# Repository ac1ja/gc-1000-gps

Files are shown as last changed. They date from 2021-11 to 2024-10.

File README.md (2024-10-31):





# Firmware
Requires platformio, make

Install build deps
```
# Ubuntu/Debian
sudo apt install build-essential make

# Platformio install script, see https://docs.platformio.org/en/latest/core/installation/methods/installer-script.html
python3 -c "$(curl -fsSL https://raw.githubusercontent.com/platformio/platformio/master/scripts/get-platformio.py)"
```

Or install platformio from [here](https://platformio.org/install), this project assumes
only pio core but the ide integrations will also work

## Build

Clone and build the repo
```
git clone --recurse-submodules https://github.com/ac1ja/gc-1000-gps.git
cd firmware
make
make flash
```

Debugging notes
```
git clone --recurse-submodules https://github.com/ac1ja/gc-1000-gps.git
cd firmware
make debug
```

See docs for full instruction! https://gc-1000-gps.readthedocs.io/en/latest/

# Hardware

## Install KiCAD

Install KiCAD from [here](https://www.kicad.org/download/), find the hardware files under `hardware`

# Where is everything?

```shell
├── cad                     # CAD and design files
├── firmware                # Software and Firmware source code
└── hardware                # PCB And component design files
    └── gc-1000-gps         # GC-1000-gps board!
        └── Libraries       # External kicad libs
```

# Docs
Docs written with sphinx for use with readthedocs.
Info here https://docs.readthedocs.io/en/stable/intro/getting-started-with-sphinx.html

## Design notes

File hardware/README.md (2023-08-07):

# Hardware

All the hardware for the inverted pendulum is made with (KiCAD)[https://www.kicad.org/]!

All the automation for this project is done with (KiBot)[https://github.com/INTI-CMNB/KiBot]

## Getting Started

Always clone this repo using submodules!

```shell
git clone --recurse-submodules https://github.com/ac1ja/gc-1000-gps.git
```

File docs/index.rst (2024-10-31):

.. GC-1000-GPS documentation master file, created by
   sphinx-quickstart on Thu Jul 22 12:23:04 2021.
   You can adapt this file completely to your liking, but it should at least
   contain the root `toctree` directive.

Welcome to GC-1000-GPS's documentation!
=======================================

.. toctree::
   :maxdepth: 3
   :glob:

   usage/getting-started
   assembly/circuit_board
   assembly/firmware
   usage/usage
   development/contributing

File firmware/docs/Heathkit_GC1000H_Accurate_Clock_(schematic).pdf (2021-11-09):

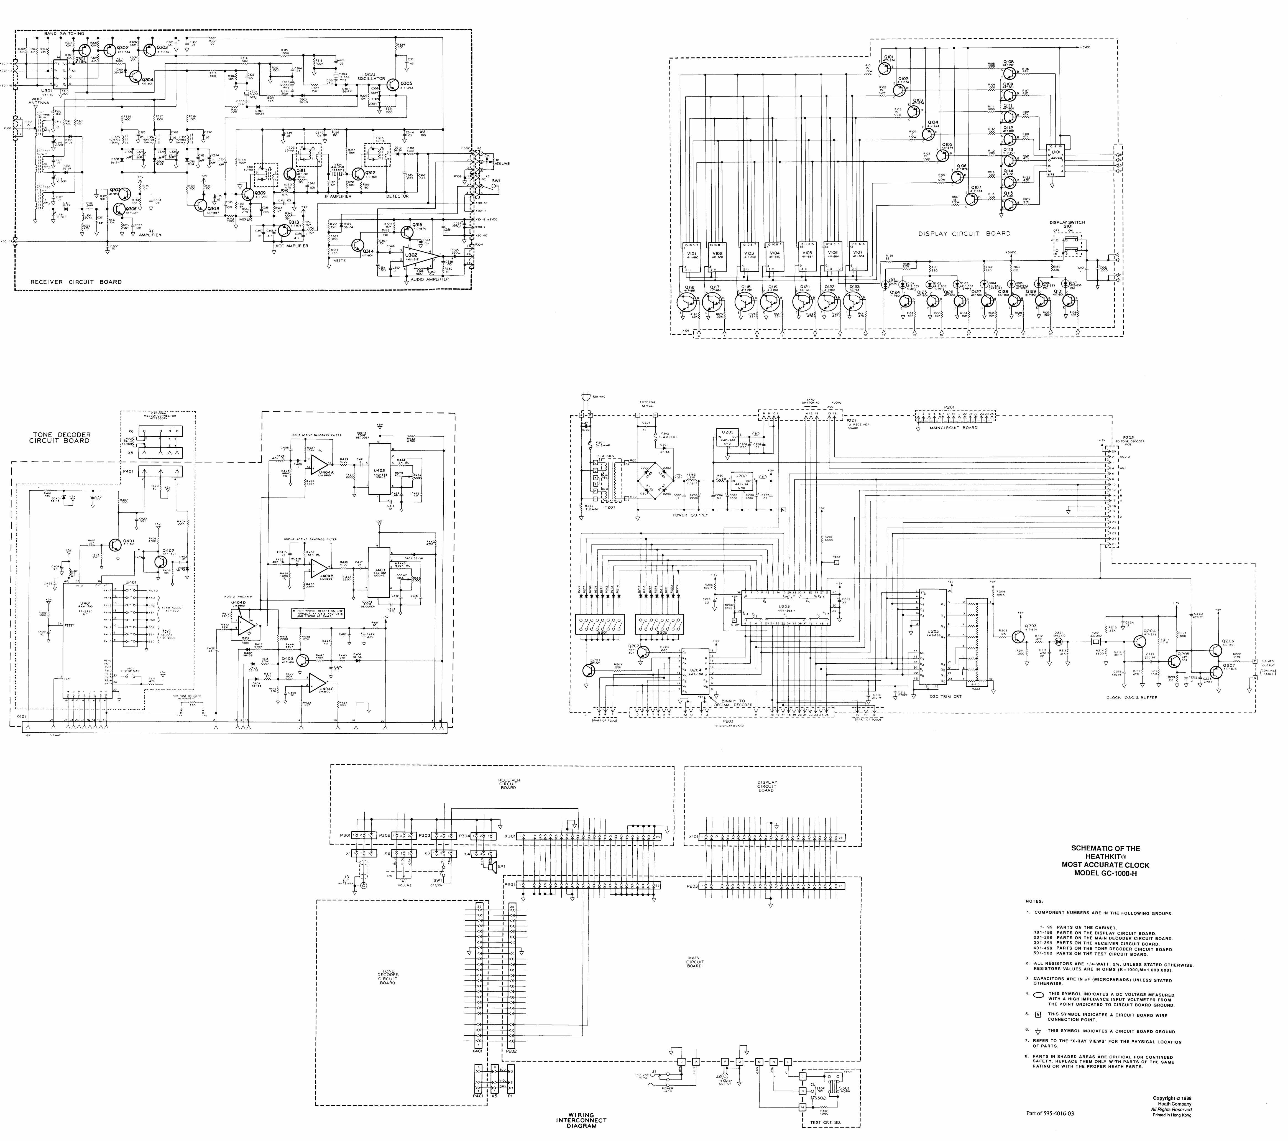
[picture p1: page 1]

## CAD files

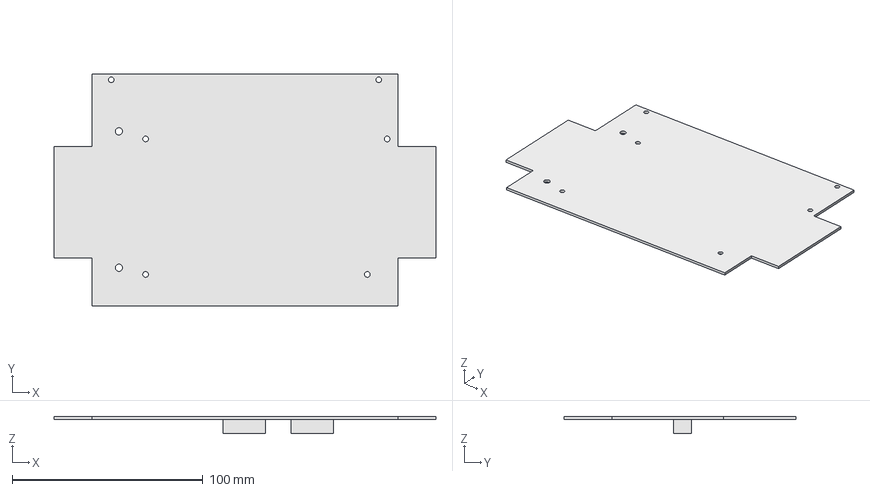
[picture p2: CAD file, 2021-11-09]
cad/gc-1000-gps_mainboardMask.FCStd
200.2 x 121.5 x 9.05 mm

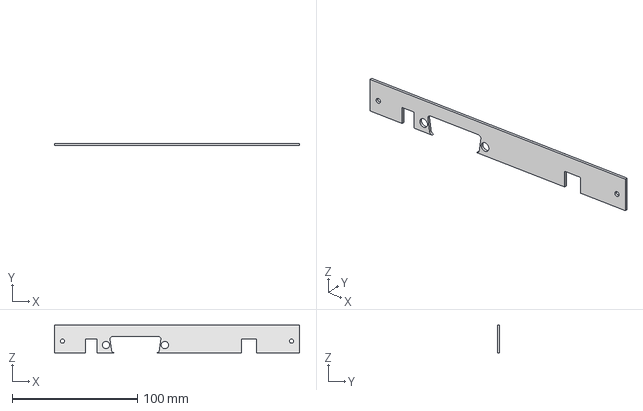
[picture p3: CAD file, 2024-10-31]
cad/gc-1000-gps_IO_Shield.FCStd
195.6 x 1.65 x 22.0 mm

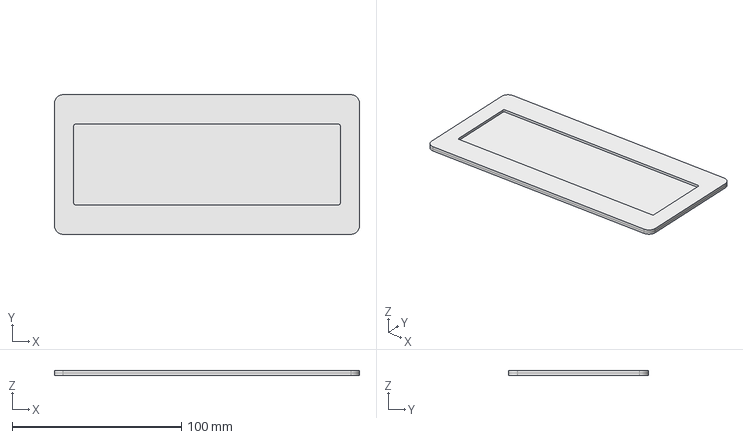
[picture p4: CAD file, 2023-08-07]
hardware/Stencil.FCStd
180.3 x 82.6 x 3.17 mm

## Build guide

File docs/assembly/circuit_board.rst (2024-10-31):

Assemble the GC-1000-GPS
========================

You've got your hands on a gc-1000-gps circuit board! Congrats! We hope you like it.

For these instructions, you will need:

* Solder and soldering iron.
* all included components.
* an `Arduino Mega <https://store.arduino.cc/usa/mega-2560-r3>`_ plugged into your computer.
* All dependencies_ required to build the code.

.. warning::
    This section of the documentation is applicable only to ``v0.2``
    boards and above, and firmware versions ``v0.2-x``.

Soldering the new board
#######################

.. note::
    It can be very helpful to install the DIP switches last, as they make it awkward when assembling the parts on the top of the board.

Prepare the board to be soldered, collect all components, heat your iron. We recomend solid core solder, and flux paste.

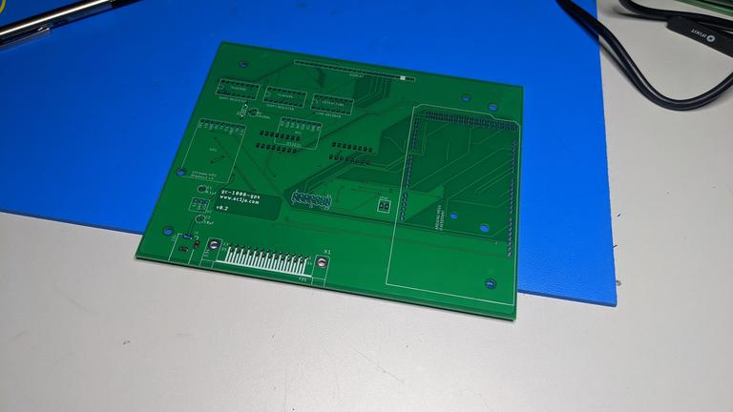
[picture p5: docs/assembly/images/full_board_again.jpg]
Full Board


I installed the chips and sockets first but a specific order is not required. 

Generally its easier to install the shorter components first.

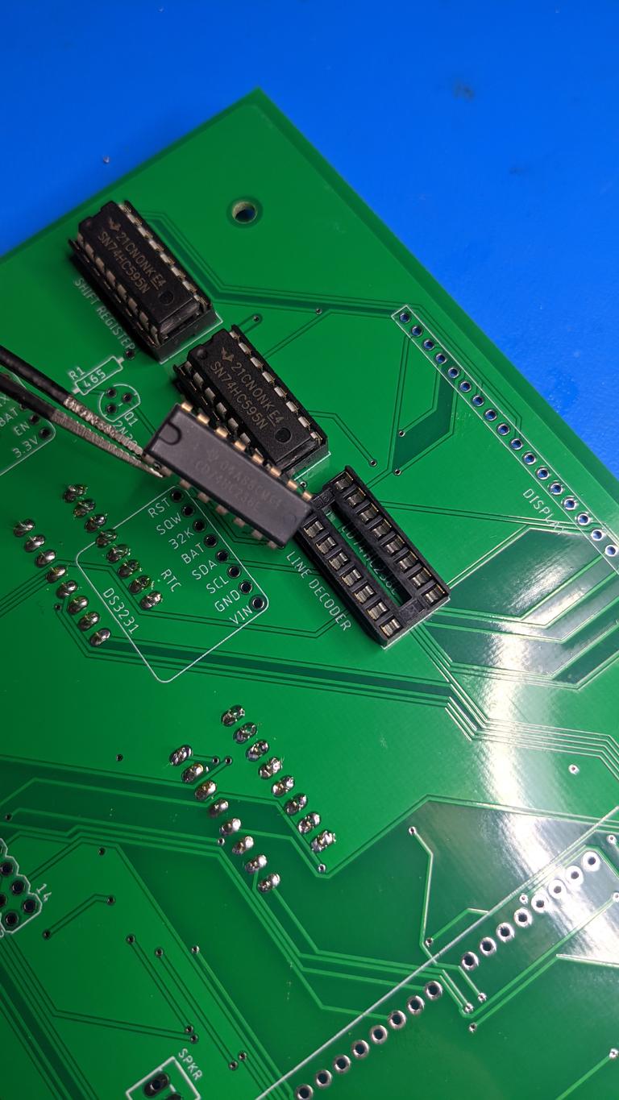
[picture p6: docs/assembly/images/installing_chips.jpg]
Installing chips


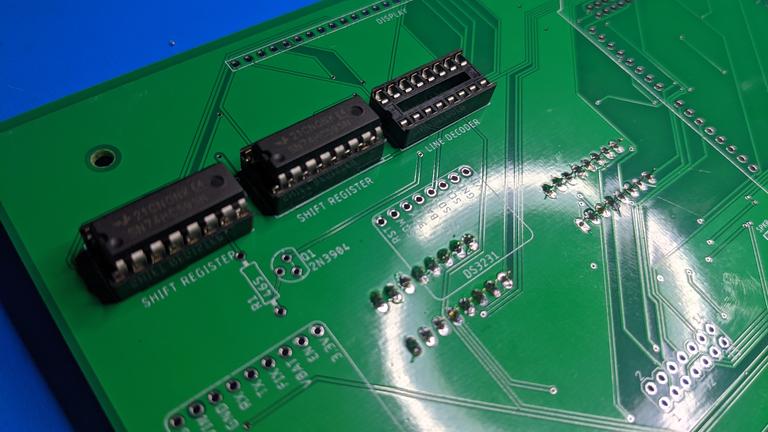
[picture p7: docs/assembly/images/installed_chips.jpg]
Chips installed


Once the chips are done, installing all of the headers are generally best.

When soldering the arduino mega pins, to assure alignment, 
it can be helpful to populate all of its pins first. Once this is done, place it on the board and solder from behind.

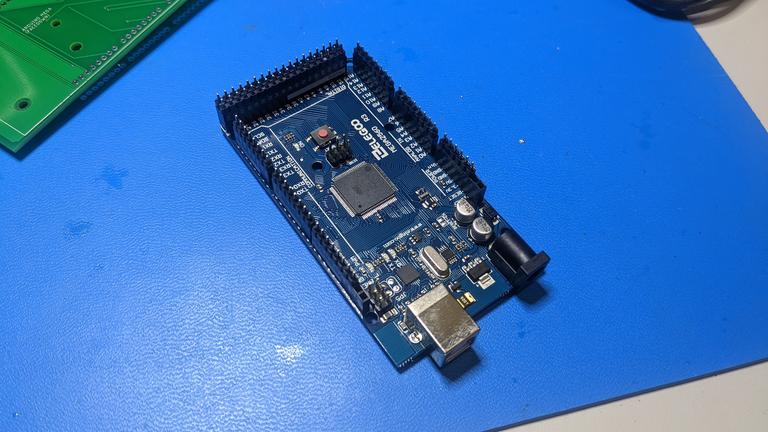
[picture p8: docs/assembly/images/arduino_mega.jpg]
Arduino Mega with pins installed


After soldering the pins, when you remove the mega, all should be straight and alligned to fit inside it.

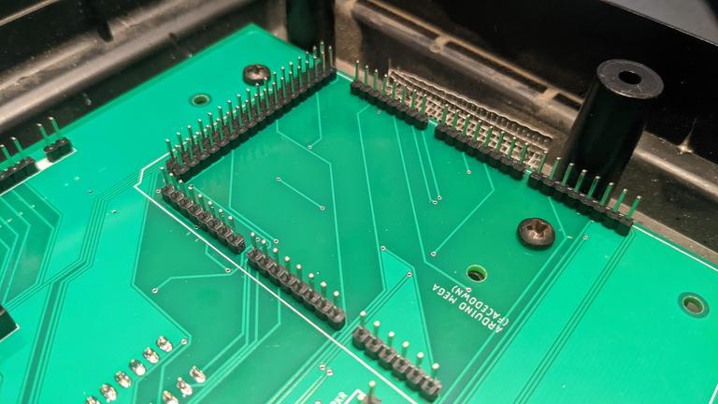
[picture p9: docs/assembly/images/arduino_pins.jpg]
Arduino Mega pins on board


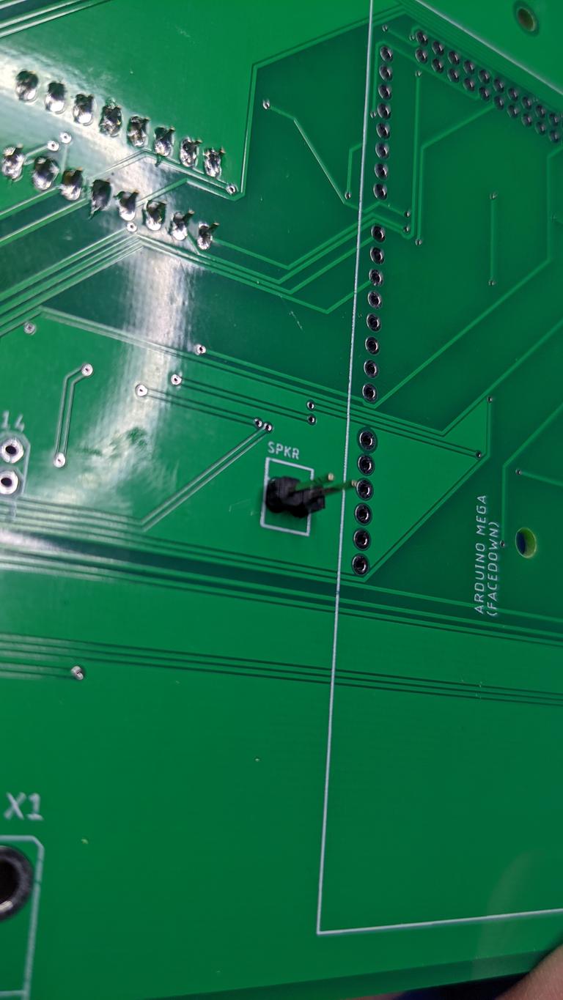
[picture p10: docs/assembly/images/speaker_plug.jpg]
Speaker pins


.. note::
    The display board also needs male header pins.

Several components such as the VRM, the GPS and the RTC need **female** header pins, install these next.

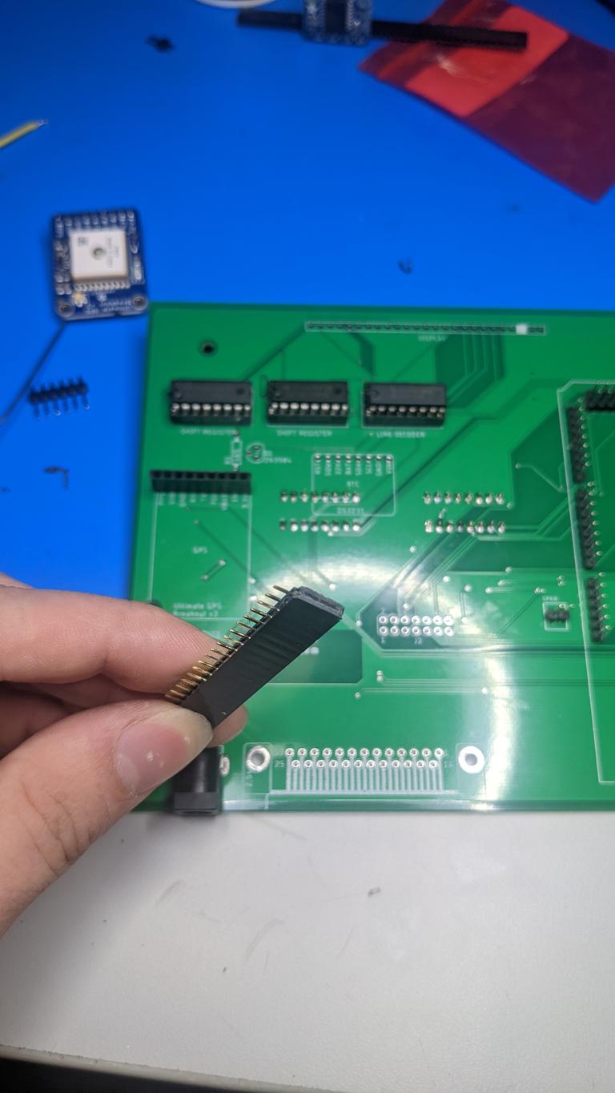
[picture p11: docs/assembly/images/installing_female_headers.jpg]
Female headers


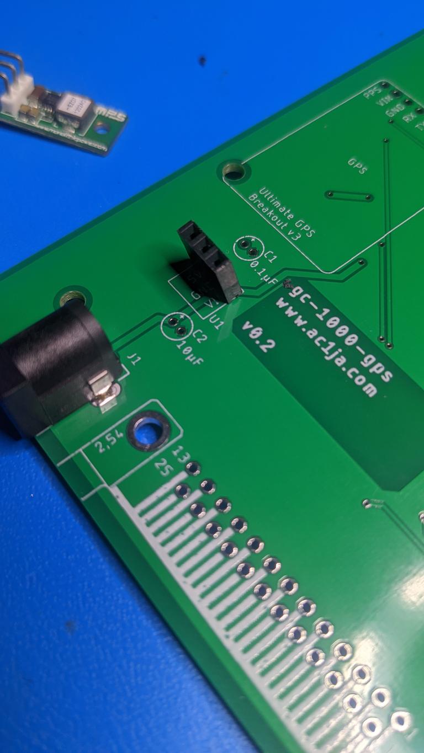
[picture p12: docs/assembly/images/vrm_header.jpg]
VRM Header


Open the packaging for the GPS and RTC from adafruit, solder on the male pins and optionally, clock battery covers.

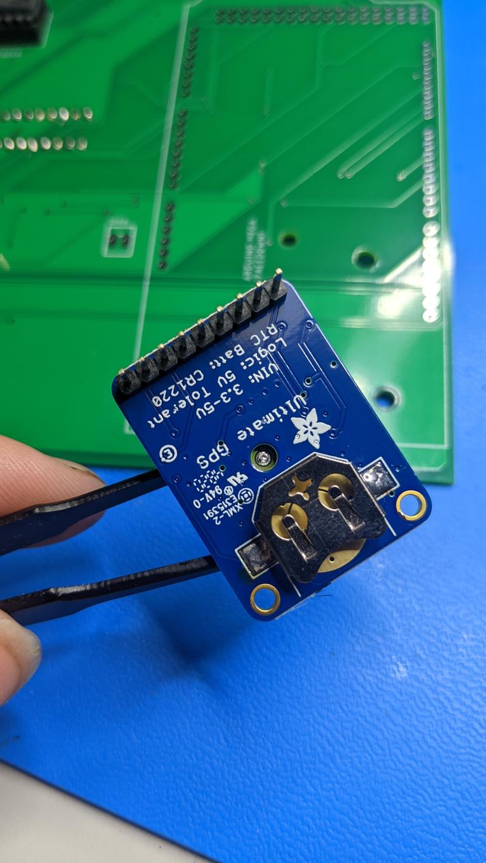
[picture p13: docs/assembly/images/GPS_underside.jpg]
GPS underside


The board is nearly complete, all components should look like this:

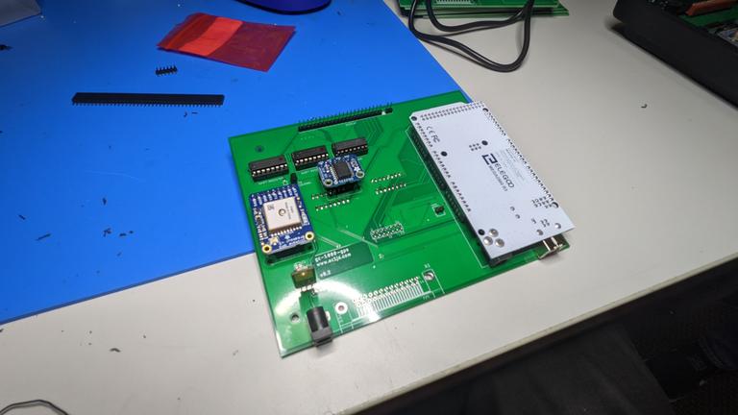
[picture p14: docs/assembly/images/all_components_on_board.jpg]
All components on board


The last step should be to install the dip switches, take note of the indicated direction.

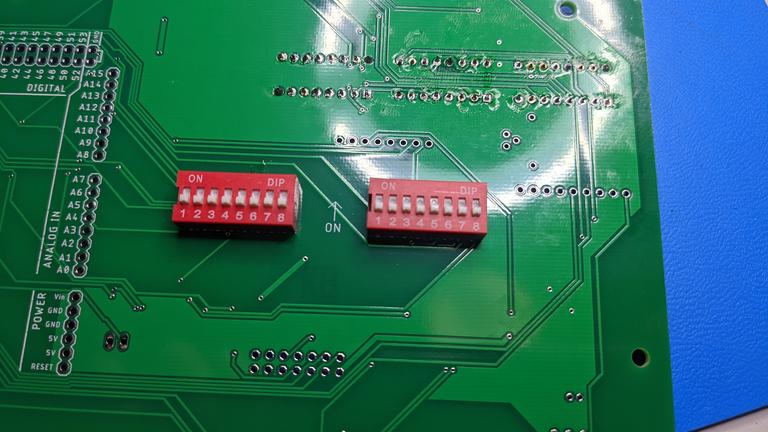
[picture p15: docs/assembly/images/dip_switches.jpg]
Dip Switches


Thats it! move onto the next step, :ref:`Dissasembly/Upgrade`.

Dissasembly/Upgrade
###################

Before we can begin assembly of your gc-1000-gps, we need to dissasemble it.

Find the four screws installed on the bottom, unscrew them to remove the cover.

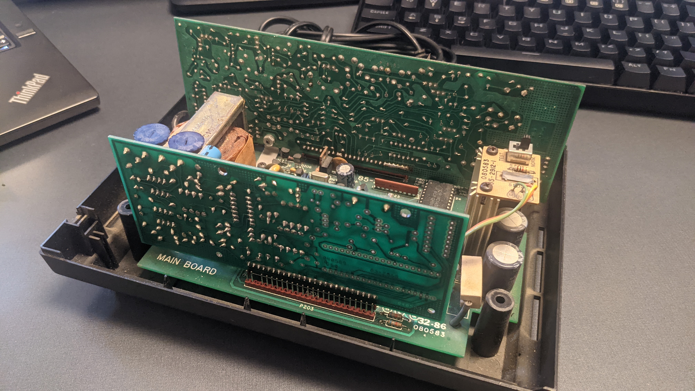
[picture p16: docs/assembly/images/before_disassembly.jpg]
Cover Removed


Once the cover is removed, remove the **display board** and put it aside.

Remove the circuit board by unscrewing the **four small plastic screws** and the **two metal screws** attaching the transformer to the case.

You should be left with just the bottom case!

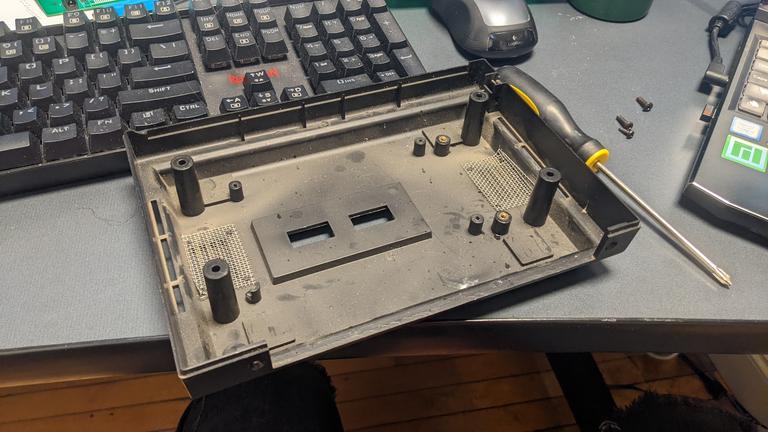
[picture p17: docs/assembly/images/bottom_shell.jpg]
Bottom Shell


Install the GC-1000-GPS upgrade board and install all 6 screws you removed in the previous step.

Install the display board on the upgrade board.

.. warning::
    The display board connector can be fragile, take care when installing it.

With the display board installed, replace the top cover (making
sure to **plug the speaker into the new speaker header**).

Then reinstall the 4 screws on the bottom, and, you're done! Congrats!

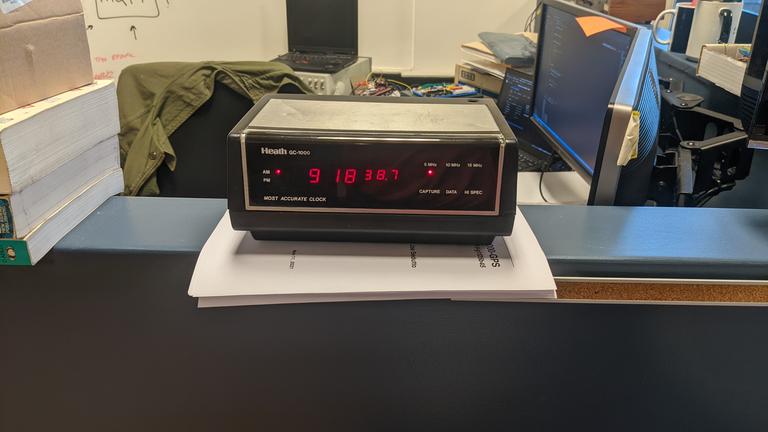
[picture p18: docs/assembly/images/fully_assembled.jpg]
Fully Assembled


The next step is :ref:`Loading the Firmware`.

.. _dependencies: https://github.com/ac1ja/gc-1000-gps#setup

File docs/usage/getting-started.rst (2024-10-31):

Getting Started
===============

The GC-1000-GPS is a drop-in replacement board for the GC-1000 radio disciplined clock, giving
some life and utility back to your super accurate radio synchronized clock!

Where to start?
---------------

Once you have a kit, check out the :ref:`Assemble the GC-1000-GPS` section 
to begin the process of installing and configuring your board for the first time!

How it works
============

The original GC-1000 synced with the WWV station in colorado for precise control over the disciplined oscillator.
The GC-1000-GPS board uses GPS to accomplish much the same goal, syncing a local RTC to use as a high precision
source and not drifting over time.

Sequence Diagram
----------------

.. mermaid::

   sequenceDiagram
      participant GPS
      participant Arduino
      participant RTC

      Arduino->>RTC: Is sync required?
      RTC-->>Arduino: Check if RTC is not synced,<br/>time between sync is too long,<br/>or gps is available
      
      Arduino-->>GPS: Check if GPS is ready<br/>Sat number, last time, etc
      GPS->>Arduino: Crack a valid gps time
      Note left of GPS: GPS may not have<br/>valid sync yet.<br/>Arduino will wait here.
      Note right of Arduino: We set a flag here and advance the<br/>second counter. We will wait for the GPS<br/>Inturrupt to trigger
      Arduino->>Arduino: Set SyncReady Flag
      critical Inturrupt Sequence
        GPS-)Arduino: PPS inturrupt!
        RTC-->>Arduino: Compare time to rtc to calculate drift
        Arduino-)RTC: Set precise time.
      end
      
GPS Time Spec
-------------

The gps time spec is formatted like such...

Disciplined Oscillator
----------------------
.. note::

   The current revision of boards do NOT have a disciplined oscillator mode.
   This may be changed in the future!

Extra tidbits
=============

* Original Manual + schematics :download:`pdf <../../gc-1000-gps/docs/Heathkit_GC1000H_Accurate_Clock_(schematic).pdf>`.
* `PRC68.com/Brooke Clarke`_ has some interesting time disecting their gc-1000 and the info was very helpful for making this project.

.. _PRC68.com/Brooke Clarke: http://www.prc68.com/I/HeathkitGC1000.shtml

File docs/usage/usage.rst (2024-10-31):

Usage
=====

Using the DIP switches
######################

On the bottom of the gc-1000-gps board there should be two banks of 16 dip switches total, their pinouts are shown below:

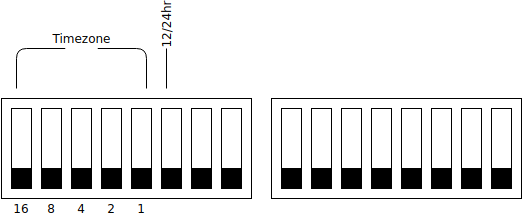
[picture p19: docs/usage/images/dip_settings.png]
Dip Settings


These switches allow the user to set the timezone and other behavior settings.

Set the timezone
################

Using the first five switches, configure your timezone offset starting from UTC-12, use the chart below

.. list-table:: gc-1000-gps timezone options
    :widths: 10 15
    :header-rows: 1
    
    * - DIP Setting
      - Timezone
    * - 00000
      - UTC-12
    * - 00001
      - UTC-11
    * - 00010
      - UTC-10
    * - 00011
      - UTC-9
    * - 00100
      - UTC-8
    * - 00101
      - UTC-7
    * - 00110
      - UTC-6
    * - 00111
      - UTC-5
    * - 01000
      - UTC-4
    * - 01001
      - UTC-3
    * - 01010
      - UTC-2
    * - 01100
      - UTC-1
    * - 01101
      - UTC
    * - 01110
      - UTC+1
    * - 01111
      - UTC+2
    * - 10000
      - UTC+3
    * - 10001
      - UTC+4
    * - 10010
      - UTC+5
    * - 10011
      - UTC+6
    * - 10100
      - UTC+7
    * - 10101
      - UTC+8
    * - 10110
      - UTC+9
    * - 10111
      - UTC+10
    * - 11000
      - UTC+11
    * - 11001
      - UTC+12
    * - 11010
      - NOT IMPLEMENTED
    * - 11011
      - NOT IMPLEMENTED
    * - 11100
      - NOT IMPLEMENTED
    * - 11101
      - NOT IMPLEMENTED
    * - 11110
      - NOT IMPLEMENTED
    * - 11111
      - NOT IMPLEMENTED

While fractional timezones are currently not settable via dip switches, we welcome
users to submit a PR to add aditional timezones to the list, see :ref:`Contributing`.

Set the 12/24 format
####################

Optionally, you can change the clock from 12 to 24 hour mode using pin 6 on the first dip switch.
See the diagram above.

The User Header
###############

Introduced in ``v0.1-lw-90`` a 2x7 pin header on the board allows user expandability with several analog and digital pins arranged in this arrangement.

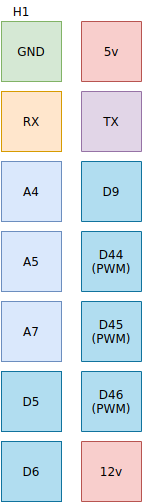
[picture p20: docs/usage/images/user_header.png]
User Header


The mega's ``serial`` interface is also broken out onto this user header to allow for even more functionality.

Functions of the lights
#######################

Because gc-1000-gps is also a hardware replacement, some lights have new functions, see diagram below.

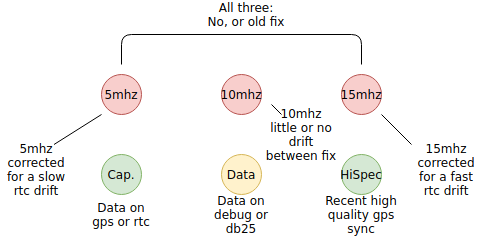
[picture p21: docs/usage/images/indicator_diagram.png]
Indicator lights


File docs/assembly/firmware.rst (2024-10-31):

Loading the firmware
====================

There are four methods for getting the firmware, you can download a precompiled release, compile graphically,
compile from a release, or build from ``main`` directly.

Flash a precompiled binary
##########################

This method is generally the easiest.

.. note::
  If you purchased a kit from us, you do not need to flash a new version unless a newer version is released.

Start by downloading a binary file from github

.. note::
  As long as you are flashing over USB/UART you do not need the .hex file with bootloader, only those
  who are flashing ISP need this hex file.

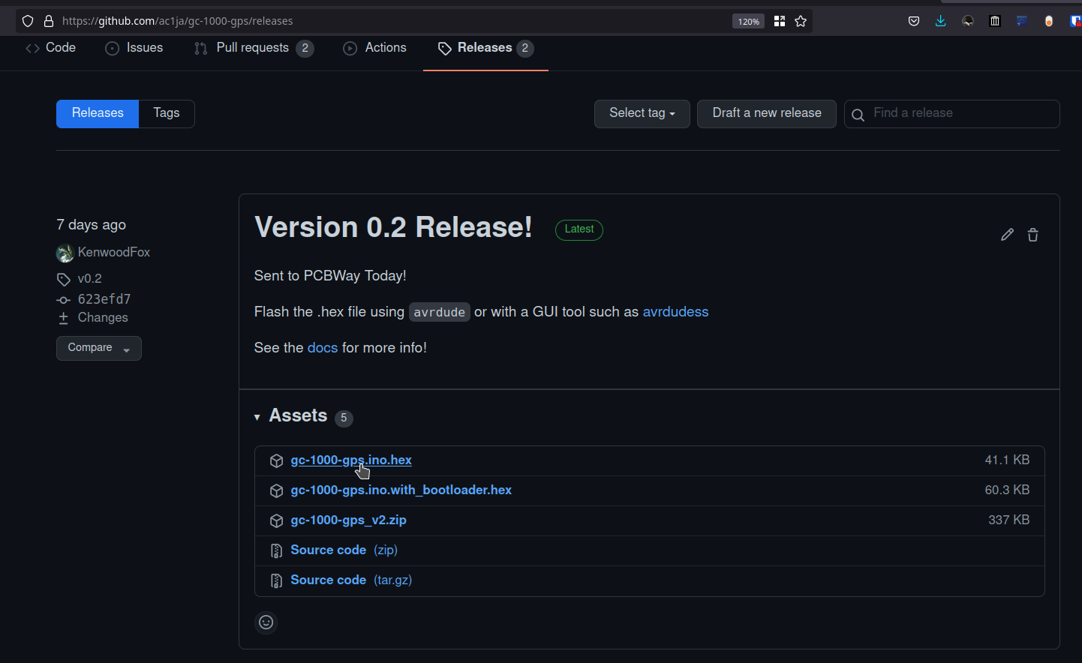
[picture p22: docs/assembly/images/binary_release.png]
Binary release


You can flash via a gui tool such as AVRDUDESS_ or avrdude, **you will need to have at lease one of 
these programs installed.**

.. tabs::

   .. group-tab:: Linux

    Download the precompiled hex and flash it using avrdude.

    .. tabs::

      .. code-tab:: shell
         
         # Flashing with avrdude
         avrdude -p m2560 -c stk500v2 -P /dev/ttytACM0 -b 115200 -F -U flash:w:/path/to/gc-1000-gps.hex

   .. group-tab:: Windows

      Using a tool like AVRDUDESS_ on windows is the easiest way to load the hex file.

Build from a release
####################

To build from a release, go to the releases_ page on our github, and select the source code for 
our most recent release.

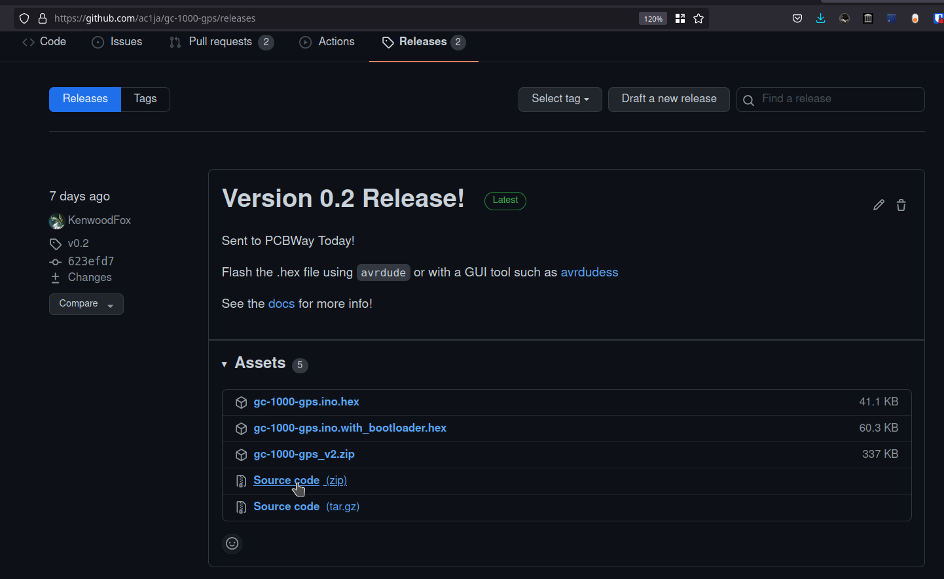
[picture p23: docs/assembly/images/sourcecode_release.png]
Releases Screenshot


Download a copy of the sourcecode and extract it to your computer.

Open a terminal in the extracted repository. The firmware is built and managed using Platformio, If
you don't have platformio, see the dependencies_ section to install it on your machine.

.. code-block:: shell

    cd firmware
    make
    make upload

Build from ``main``
###################

Building from the main branch may result in more experimental but more up to date features and stability.

Start by cloning the repo down, then CD to the build location and build the code. Use the same steps
as above.

.. tabs::

   .. group-tab:: Linux

    Start by installing pio-core_ for your system, then.

    .. tabs::

      .. code-tab:: shell
         
          git clone https://github.com/ac1ja/gc-1000-gps
          cd gc-1000-gps/firmware
          make
          make upload

   .. group-tab:: Windows

      Download vs-code_ and install the pio-extension_.

      Use ``git clone`` to clone the repo, or download the latest version of
      ``main`` as a `.zip file`_.

      Open the ``gc-1000-gps/firmware`` directory in vscode. Then invoke platformio upload
      or press ``alt+ctrl+u``.

Troubleshooting
###############

If you get an error such as ``avrdude: ser_open(): can't open device "unknown": No such file or directory`` 
your mega might not be plugged in or may not have enough power over usb to turn on.

If you get an error such as ``command not found: arduino-cli`` make sure you installed all dependencies_. 

.. _dependencies: https://github.com/ac1ja/gc-1000-gps#setup
.. _releases: https://github.com/ac1ja/gc-1000-gps/releases
.. _AVRDUDESS: https://github.com/zkemble/AVRDUDESS
.. _pio-core: https://docs.platformio.org/en/latest/core/installation/index.html
.. _vs-code: https://code.visualstudio.com/
.. _pio-extension: https://platformio.org/install/ide?install=vscode
.. _.zip file: https://github.com/ac1ja/gc-1000-gps/archive/refs/heads/main.zip

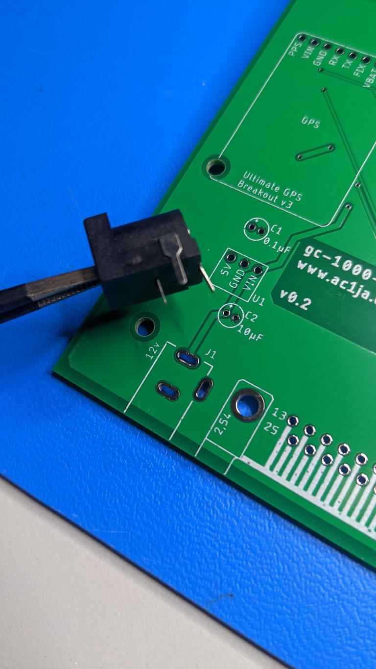
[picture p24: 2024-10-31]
docs/assembly/images/installing_barrel_jack.jpg

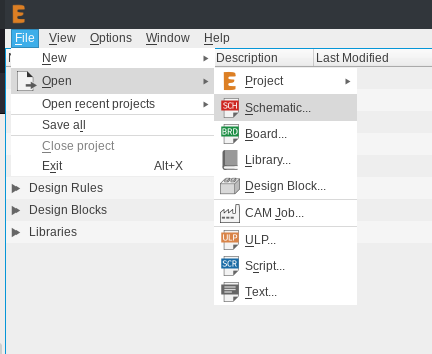
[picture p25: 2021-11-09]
docs/development/images/eagle_tutorial/load_sch.png

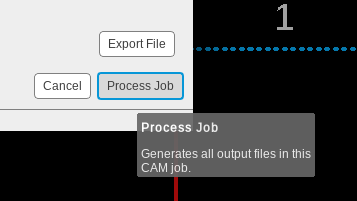
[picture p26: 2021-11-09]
docs/development/images/eagle_tutorial/process_job.png

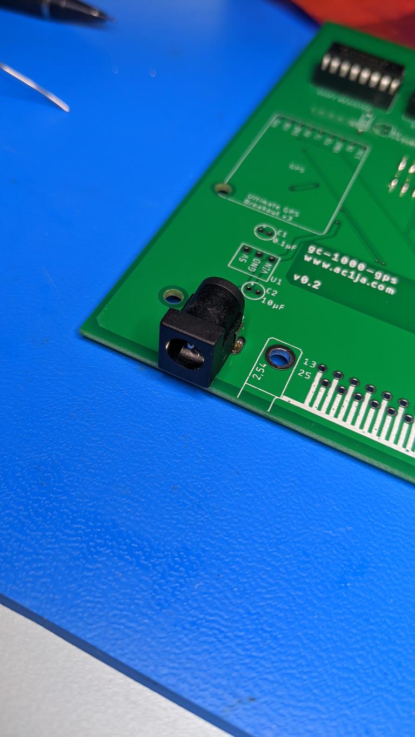
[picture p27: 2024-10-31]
docs/assembly/images/barrel_jack.jpg

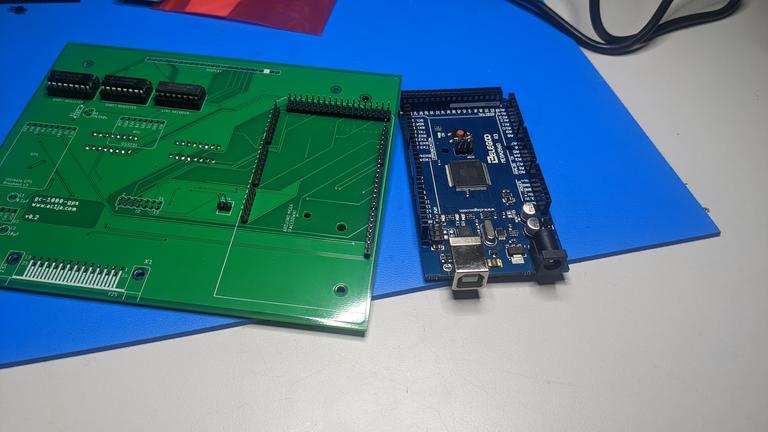
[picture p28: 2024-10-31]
docs/assembly/images/ready_to_assemble_arduino.jpg

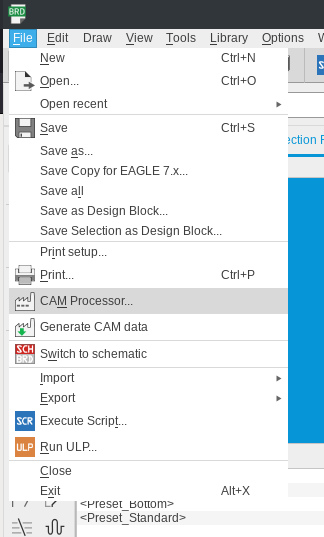
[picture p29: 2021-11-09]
docs/development/images/eagle_tutorial/open_cam_processor.png

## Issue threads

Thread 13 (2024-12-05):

Docs need improvement

KenwoodFox, 2024-12-05:
- [ ] Missing sections for updating firmware
 - [ ] Cleaned up build instructions
 - [ ] Schematic and better flowchart
 - [ ] Attach full BOM (kibot export) to docs

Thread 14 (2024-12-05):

Timezone Library

KenwoodFox, 2024-12-05:
Couple of issues with the timezone library.

Timezone TZ `TCR*` isn't being used correctly (or sometimes at all!) in the actual UTC logic conversion, this is bad! because we rely on only the TZ lib for proper DST corrections!

I see two options for a real, solid fix (one that will make the gc-1000-gps reliable and understandable)

## Option "Old School Cool"
Use the TZ lib fully, including for localization, this would mean reverting some progress made in recent months to force our own robust localization code

## Option "Do it ourselves but better"
Try to move away from the TZ lib, since we really only need its database of DST data, we could **leverage that data directly** or more simply, just backpack on the tz lib to tell if we're shifted by a DST rule for the owner's current location.

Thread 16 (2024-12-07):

Leading Zero when GMT/Full Mode

KenwoodFox, 2024-12-07:
We want to emulate the original function, so we must display leading zeros when in GMT mode (Full formatted time)

Ours (bug)
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

Original
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

KenwoodFox, 2025-01-02:
AM/PM bug still present.
Leading zero bug (same code)

https://github.com/user-attachments/assets/345fe81d-57b9-46f0-8841-9b518d6b0e3c

KenwoodFox, 2025-01-03:
Reports issue kinda worse, am/pm system all messed up

Gonna track fixes in another branch.. incredibly tangled

KenwoodFox, 2025-01-03:
Some thoughts:

https://github.com/ac1ja/gc-1000-gps/blob/93880a2e835946f719b9001f15e3815e9e12bb68/firmware/lib/display/display.cpp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

This is messy, it doesn't look neat/function smoothly to have weird exceptions for specific things going on in a place like this. And the more of them we have, the more bugs and regression we have. I think this needs to move up a stage.

And, speaking of moving up a stage

https://github.com/ac1ja/gc-1000-gps/blob/93880a2e835946f719b9001f15e3815e9e12bb68/firmware/src/main.cpp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

This is not very helpful, having **three** systems of tracking am/pm, meridan and *use24hrmode* is extremely confusing and leading to a LOT of issues.

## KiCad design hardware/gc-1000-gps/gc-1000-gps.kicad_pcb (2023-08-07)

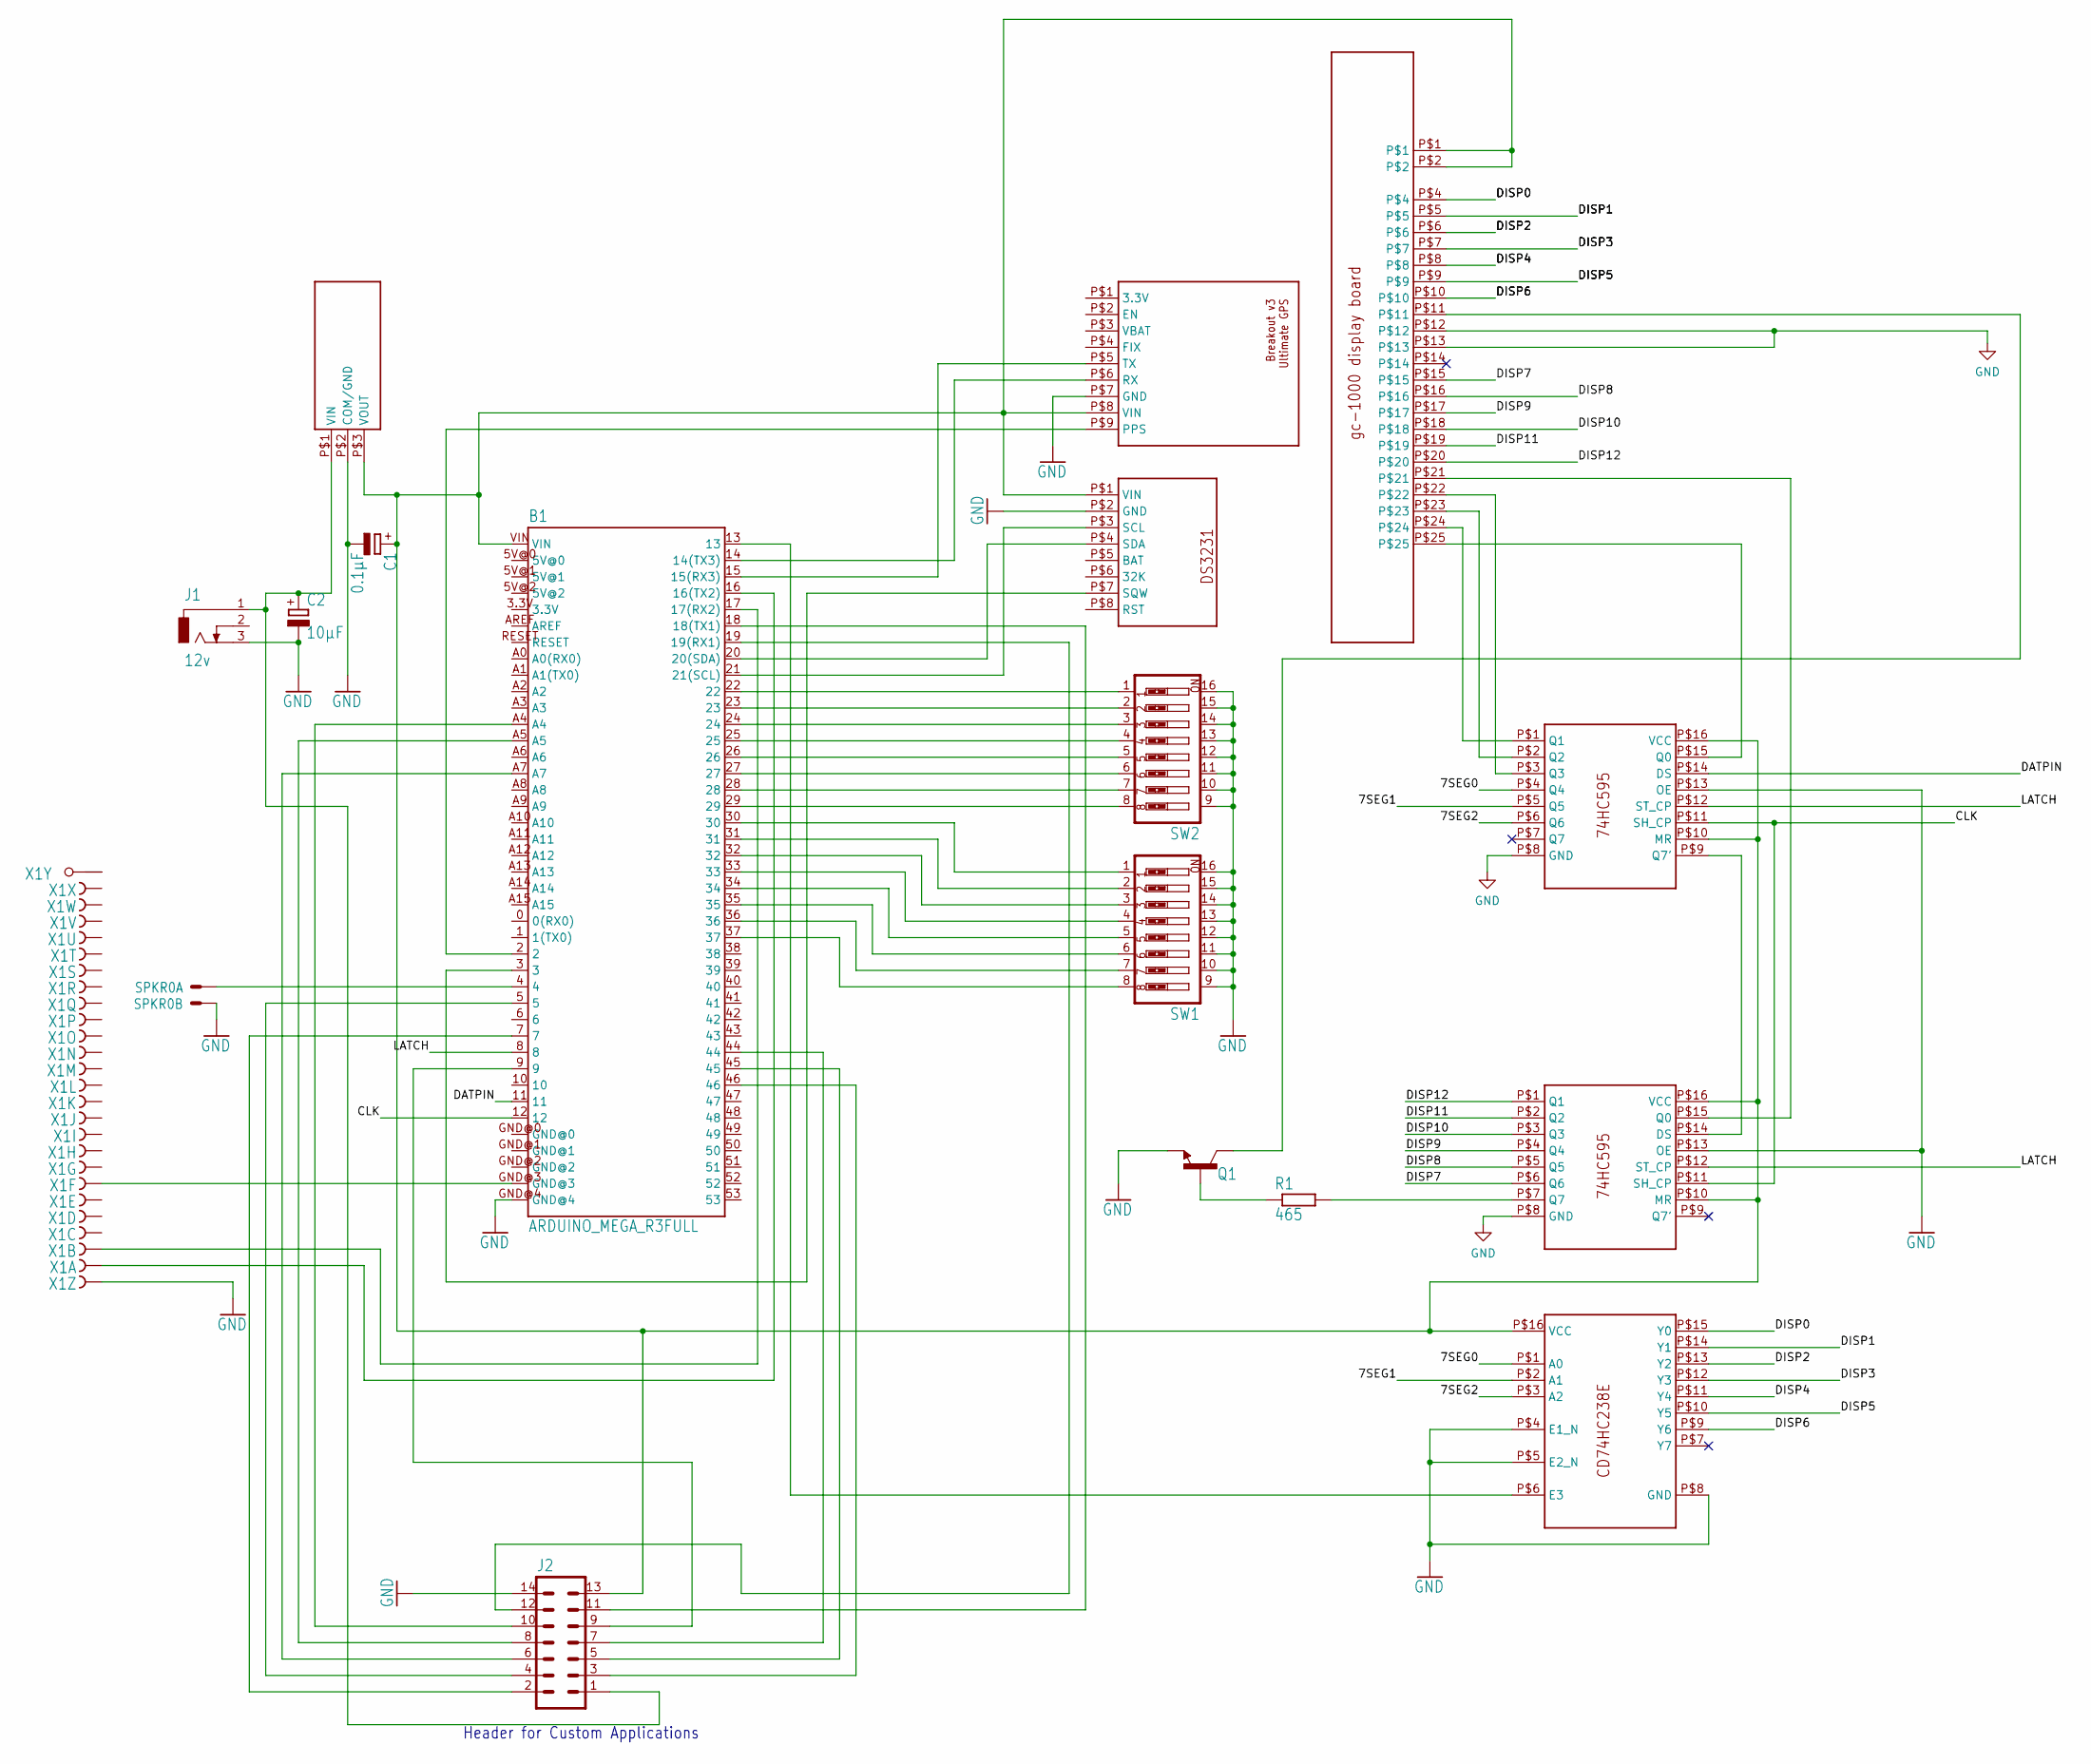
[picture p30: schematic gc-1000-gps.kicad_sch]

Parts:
B1: ARDUINO_MEGA_R3FULL; ARDUINO_MEGA
C1: 0.1µF; E1,8-4
C2: 10µF; E1,8-4
J1: 12v; DCJ0303
J2: MA07-2
Q1: 2N3904; TO92
R1: 465; 0207_10
SPKR0: 22-23-2021
SW1, SW2: SW_DIP-8; EDG-08
U1: OKI-78SR
U$1: PA6H-PROTO; PA6H
U$2: CD74HC238E
U$4: DS3231
U$5: GC-1000-DISP
U$6, U$7: 74HC595
X1: F25HPS; F25HP

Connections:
5VLINE: B1.VIN, C1.+, J2.13, U1.P$3 (VOUT), U$1.P$8 (VIN), U$2.P$16 (VCC), U$4.P$1 (VIN), U$5.P$1, U$5.P$2, U$6.P$10 (MR), U$6.P$16 (VCC), U$7.P$10 (MR), U$7.P$16 (VCC)
7SEG0: U$2.P$1 (A0), U$6.P$4 (Q4)
7SEG1: U$2.P$2 (A1), U$6.P$5 (Q5)
7SEG2: U$2.P$3 (A2), U$6.P$6 (Q6)
B$2: B1.21 (21(SCL)), U$4.P$3 (SCL)
CLK: B1.12, U$6.P$11 (SH_CP), U$7.P$11 (SH_CP)
CUTOUT: B1.19 (19(RX1)), J2.12
DATPIN: B1.8, U$6.P$12 (ST_CP), U$7.P$12 (ST_CP)
DISP0: U$2.P$15 (Y0), U$5.P$4
DISP1: U$2.P$14 (Y1), U$5.P$5
DISP2: U$2.P$13 (Y2), U$5.P$6
DISP3: U$2.P$12 (Y3), U$5.P$7
DISP4: U$2.P$11 (Y4), U$5.P$8
DISP5: U$2.P$10 (Y5), U$5.P$9
DISP6: U$2.P$9 (Y6), U$5.P$10
DISP7: U$5.P$15, U$7.P$6 (Q6)
DISP8: U$5.P$16, U$7.P$5 (Q5)
DISP9: U$5.P$17, U$7.P$4 (Q4)
DISP10: U$5.P$18, U$7.P$3 (Q3)
DISP11: U$5.P$19, U$7.P$2 (Q2)
DISP12: U$5.P$20, U$7.P$1 (Q1)
GND: B1.GND@4, C1.-, C2.-, J1.3, J2.14, Q1.3 (E), SPKR0.2, SW1.9, SW1.10, SW1.11, SW1.12, SW1.13, SW1.14, SW1.15, SW1.16, SW2.9, SW2.10, SW2.11, SW2.12, SW2.13, SW2.14, SW2.15, SW2.16, U1.P$2 (COM/GND), U$1.P$7 (GND), U$2.P$4 (E1_N), U$2.P$5 (E2_N), U$2.P$8 (GND), U$4.P$2 (GND), U$5.P$12, U$5.P$13, U$6.P$8 (GND), U$6.P$13 (OE), U$7.P$8 (GND), U$7.P$13 (OE), X1.1 (F)
LATCH: B1.4, SPKR0.1
unnamed: B1.3, U$4.P$7 (SQW)
unnamed: C2.+, J1.1, J2.1, U1.P$1 (VIN)
unnamed: B1.20 (20(SDA)), U$4.P$4 (SDA)
unnamed: B1.22, SW2.1
unnamed: B1.2, U$1.P$9 (PPS)
unnamed: B1.23, SW2.2
unnamed: B1.24, SW2.3
unnamed: B1.25, SW2.4
unnamed: B1.26, SW2.5
unnamed: B1.27, SW2.6
unnamed: B1.28, SW2.7
unnamed: B1.29, SW2.8
unnamed: B1.30, SW1.1
unnamed: B1.31, SW1.2
unnamed: B1.32, SW1.3
unnamed: B1.33, SW1.4
unnamed: B1.34, SW1.5
unnamed: B1.35, SW1.6
unnamed: B1.36, SW1.7
unnamed: B1.37, SW1.8
unnamed: B1.13, U$2.P$6 (E3)
unnamed: U$5.P$21, U$7.P$15 (Q0)
unnamed: Q1.2 (B), R1.1
unnamed: R1.2, U$7.P$7 (Q7)
unnamed: Q1.1 (C), U$5.P$11
unnamed: U$5.P$22, U$6.P$3 (Q3)
unnamed: U$5.P$23, U$6.P$2 (Q2)
unnamed: U$5.P$24, U$6.P$1 (Q1)
unnamed: U$5.P$25, U$6.P$15 (Q0)
unnamed: B1.16 (16(TX2)), X1.2 (F)
unnamed: B1.17 (17(RX2)), X1.3 (F)
unnamed: B1.GND@3, X1.7 (F)
unnamed: B1.14 (14(TX3)), U$1.P$6 (RX)
unnamed: B1.15 (15(RX3)), U$1.P$5 (TX)
unnamed: B1.A5, J2.8
unnamed: B1.18 (18(TX1)), J2.11
unnamed: B1.A4, J2.10
unnamed: B1.A7, J2.6
unnamed: B1.5, J2.4
unnamed: B1.7, J2.2
unnamed: B1.9, J2.9
unnamed: B1.44, J2.7
unnamed: B1.45, J2.5
unnamed: B1.46, J2.3
unnamed: U$6.P$9 (Q7'), U$7.P$14 (DS)
unnamed: B1.11, U$6.P$14 (DS)

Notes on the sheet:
Header for Custom Applications

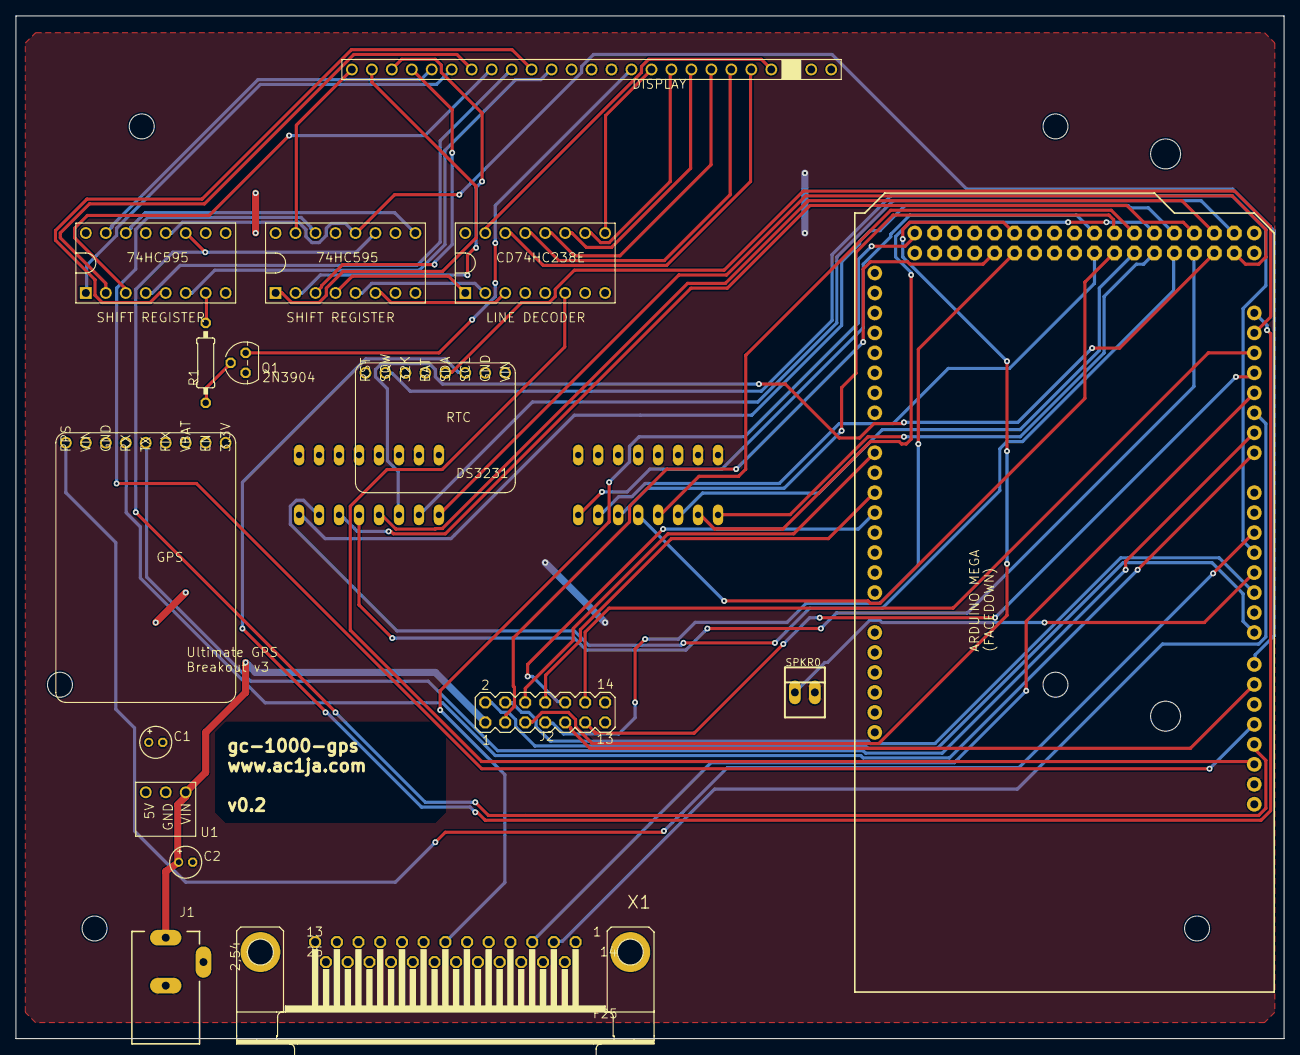
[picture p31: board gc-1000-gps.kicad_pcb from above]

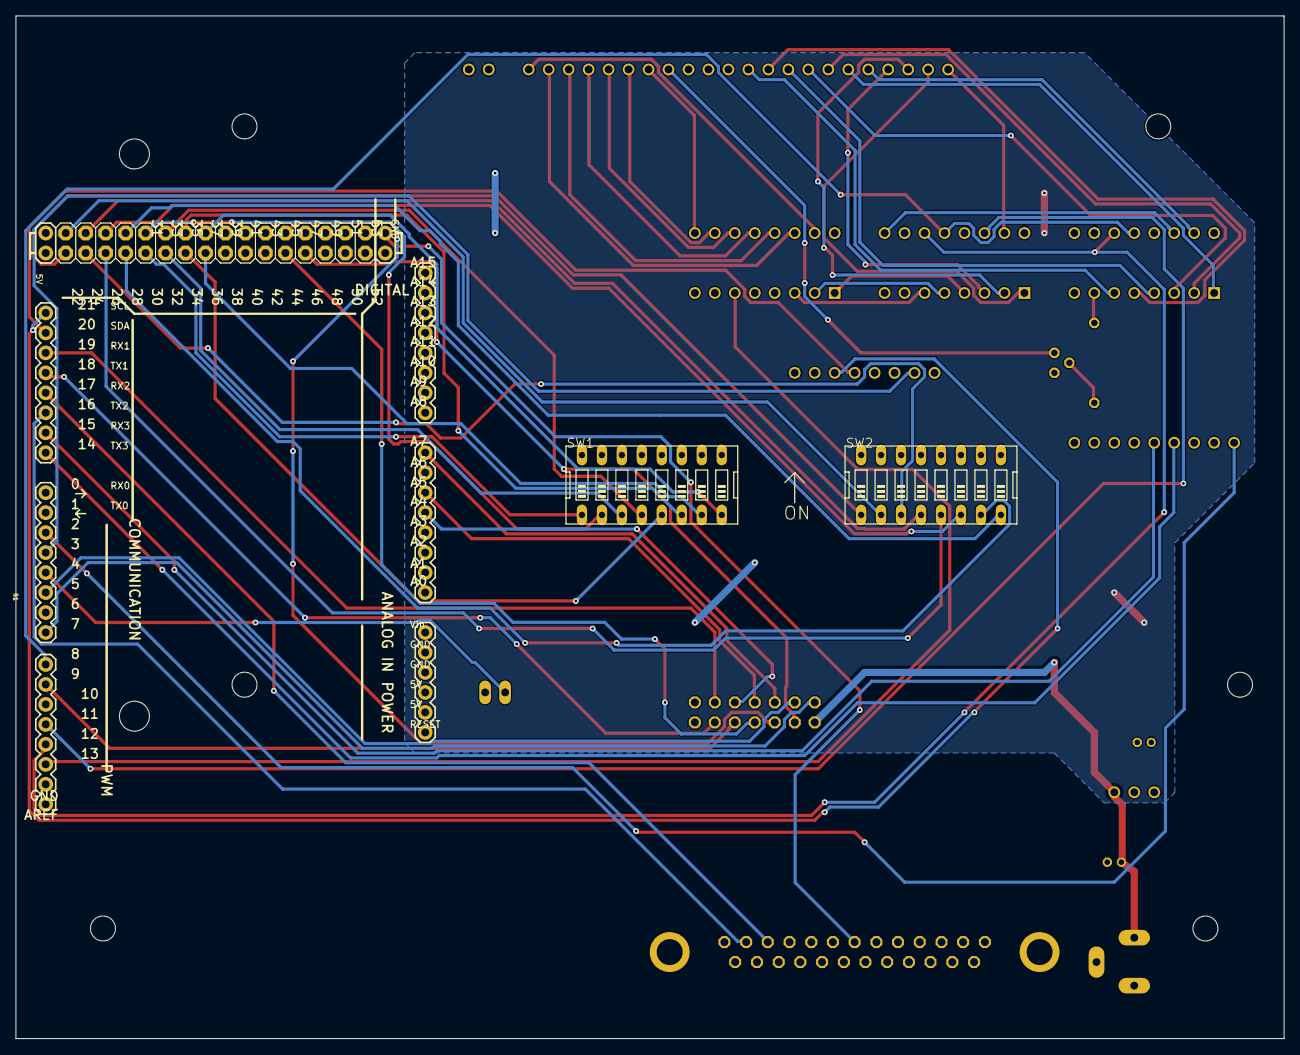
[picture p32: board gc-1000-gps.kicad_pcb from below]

Board: 2 copper layers, 161.3 x 130.1 mm, 26 parts (3 on the bottom side), 69 nets.

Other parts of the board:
@HOLE0, @HOLE1, @HOLE2, @HOLE3, @HOLE4, @HOLE5, @HOLE6, @HOLE7: (no value)

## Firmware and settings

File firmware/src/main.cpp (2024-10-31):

/**
 * @brief arduinio controlled Heathkit GC-1000 clock display driver
 * licensed under GNU GPL v3.0, https://www.gnu.org/licenses/gpl.html
 *
 * Nick Soggu
 * created march 2020
 * revised for arduino mega on 2021
 */

#include "Arduino.h"

// Libs, see platformio.ini
#include <TinyGPSPlus.h>
#include <RTClib.h>          // https://github.com/adafruit/RTClib
#include <TimeLib.h>         // https://github.com/PaulStoffregen/Time
#include <Timezone.h>        // https://github.com/JChristensen/Timezone
#include <EnableInterrupt.h> // https://github.com/GreyGnome/EnableInterrupt
#include <TimerOne.h>        // https://github.com/PaulStoffregen/TimerOne
#include <avr/wdt.h>
#include <ArduinoLog.h>

// Our libs
#include "display.h"

// Our headers
#include "boardConfig.h"
#include "buildData.h"
#include "constants.h"
#include "timezones.h"

// Timezone
TimeChangeRule dipDST = {"DST", Second, Sun, Mar, 2, -240}; // Daylight time = UTC - 4 hours TODO: Changeme
TimeChangeRule dipSTD = {"STD", First, Sun, Nov, 2, -300};  // Standard time = UTC - 5 hours TODO: Changeme
Timezone dipTZ(dipDST, dipSTD);
TimeChangeRule *tcr; // pointer telling us where the TZ abbrev and offset is

// Display
Display display(SEGMENT_ENABLE_PIN, LATCH_PIN, DATA_PIN, CLOCK_PIN);

// Hi-Spec and time age
unsigned long lastTimeSync;   // How long ago was time set
volatile bool hasTimeBeenSet; // Has the time been set

// PPS sync flag
volatile bool pps = 0;

// Time and time vars
uint8_t storedMonth, storedDay, storedHour, storedMinute, storedSecond, storedHundredths, storedTenths;
int16_t storedYear;
uint32_t storedAge; // same as fixed_afe in docs, time since fix.
volatile bool syncReady;
volatile byte lastMinute;

// Dip switch settings
bool newSettingsFlag = false;                                 // true whenever settings have been changed
unsigned int DIPsum;                                          // holds the sum value of all switches to check for when settings are changed
const byte TimeZoneInputs[] = {DIP0, DIP1, DIP2, DIP3, DIP4}; // what pins to use for the time zone inputs
int16_t timeZone;                                             // the current timezone
const byte ClockFormatInput = DIP2;                           // what pin to use to check if 24 or 12hr format
const byte LocalTZInput = DIP0;                               // what pin to use to check if we're using UTC or local TZ (TimeZoneInputs)
bool isUsingLocalTZInput = true;                              // Whether or not we're currently using the local tz input

long dipcheck = 0; // a counter to keep track of clock cycles before next update

// display lights
const byte debugSerialCheck = 1; // debug activity pin
const byte gpsSerialCheck = 15;  // gps activity pin

// hardware objects
TinyGPSPlus gps;
uint8_t satsInView = 0;
RTC_DS3231 rtc;

time_t prevDisplay = 0; // when the digital clock was displayed

byte pos = 0;
bool AM, PM;

byte localHour, localMinute, localSecond, localTens;
byte dataLED, captureLED, highSpecLED = false;

bool mhz5, mhz10, mhz15;

bool flasher()
{
  return (millis() / 400) % 2;
}

void isrPPS()
{
  // flag the 1pps input signal
  pps = true;

  // if minute has changed...allow a GPS sync to happen
  if (lastMinute != minute())
    hasTimeBeenSet = false; // Might need to refactor this? seems redundant?
}

bool isHighSpec()
{
  return (millis() - lastTimeSync < hiSpecMaxAge) && hasTimeBeenSet;
}

void pullRTCTime()
{
  DateTime _now = rtc.now();
  // Set time using old RTC value.
  setTime(_now.hour(), _now.minute(), _now.second(), _now.day(), _now.month(), _now.year());
}

void syncCheck()
{
  // Log.verboseln(F("Checking sync, pps %d, syncReady %d, hasTimeBeenSet %d, !isHighSpec %d"), pps, syncReady, !hasTimeBeenSet, !isHighSpec());

  // Checks the PPS flag, limits us to doing a syncCheck once per second.
  if (pps) // TODO: add a timeout here so we can sync even without pps signal
  {
    if (syncReady && (!hasTimeBeenSet || !isHighSpec()))
    {
      // Compute Drift
      // byte drift = storedSecond - rtc.now().second();
      int drift = storedSecond - second() - 1;

      setTime(storedHour, storedMinute, storedSecond, storedDay, storedMonth, storedYear); // Set the time? This puts this time in local
      rtc.adjust(DateTime(storedYear, storedMonth, storedDay, storedHour, storedMinute, storedSecond));

      // Display Drift
      if (abs(drift) < 0)
      {
        display.setDrift(display.SLOW);
      }
      else if (drift > 0)
      {
        display.setDrift(display.FAST);
      }
      else
      {
        display.setDrift(display.NONE);
      }

      // rtc.adjust(dipTZ.toLocal(DateTime(storedYear, storedMonth, storedDay, storedHour, storedMinute, storedSecond).unixtime())); // adjust the time to the tz.tolocal conversion of gps stored data
      adjustTime(1); // 1pps signal = start of next second

      // Skip updating the last time sync if not pps
      if (pps)
      {
        lastTimeSync = millis();
      }
      hasTimeBeenSet = true;     // Time has been set
      newSettingsFlag = true;    // New settings are in place
      syncReady = false;         // Reset syncReady flag
      lastMinute = storedMinute; // Last minute is now the stored minute

      Log.infoln("Synced! Drift was %d seconds", drift);
    }
    else
    {
      Log.warningln("PPS triggered but not ready for sync!");
    }

    pps = false;
  }
  else
  {
    // Might be nice to move this to a more periodic function if we go the RTOS route.
    pullRTCTime();
  }
}

void updateBoard(void)
{
  // read the status of comm pins
  display.setData(!digitalRead(debugSerialCheck));  // if there is data on the serial line
  display.setCapture(!digitalRead(gpsSerialCheck)); // if the gps is being read from
  display.setHighSpec(isHighSpec());                // if the time has been locked in/synced to the rtc

  // Local var use24mode (could be refactored)
  bool _use24mode = clockFormat == 24;

  display.setDispTime(isUsingLocalTZInput ? meridianTime(getUTCOffsetHours(hour()), _use24mode) : meridianTime(hour(), _use24mode),
                      isUsingLocalTZInput ? getUTCOffsetMinutes(minute()) : minute(),
                      second(),
                      isHighSpec() ? (((millis() - lastTimeSync) / 100) % 10) : flasher() ? 99
                                                                                          : satsInView);

  // Setting the AM/PM lights
  if (!_use24mode)
  {
    display.setMeridan(getAM(hour()), !getAM(hour()));
  }
  else
  {
    display.setMeridan(false, false);
  }

  display.updateBoard();
}

void setup()
{
  // initalize Serial interfaces
  Serial.begin(115200); // USB (debug)
  Serial3.begin(9600);  // GPS

  // Setup logging
  Log.begin(LOG_LEVEL_VERBOSE, &Serial);
  Log.noticeln("Serial started.");

  // inatialize input pins
  pinMode(GPS_PPS_PIN, INPUT); // GPS PPS signal

  // initalize I/O pins
  DDRA = 0x00;
  PORTA = 0xFF; // ALl PORTA pins HIGH
  DDRC = 0x00;
  PORTC = 0xFF; // ALl PORTC pins HIGH
  pinMode(debugSerialCheck, INPUT);
  pinMode(gpsSerialCheck, INPUT);
  Log.noticeln("Initalized all I/O pins");

  // start rtc
  rtc.begin();
  Log.noticeln("Started RTC.");

  lastTimeSync = millis() + hiSpecMaxAge;
  hasTimeBeenSet = false;

  // clear screen
  // dataOut = 0;
  // shiftOut(DATA_PIN, CLOCK_PIN, dataOut);

  enableInterrupt(GPS_PPS_PIN, isrPPS, RISING); // Attach interrupt to gps PPS pin
  Log.noticeln("Initalized all inturrupts");

  // print out some information about the software we're running.
  Log.noticeln(MOTD);

  // don't sync the time yet...
  syncReady = false;
  hasTimeBeenSet = false;
  lastMinute = -1;

  // Configure watchdog
  wdt_enable(WDTO_2S);

  // initalize inturrupts
  Timer1.initialize(3000);             // Cycle every 3000μs
  Timer1.attachInterrupt(updateBoard); // Attach an interrupt to callback updateBoard()

  // Quick-load rtc time at boot
  pullRTCTime();
}

void loop()
{
  // if we have not yet set the time OR if the current time is out of date
  if (!hasTimeBeenSet || !isHighSpec())
  {
    while (Serial3.available())
    {
      char c = Serial3.read();
      // Serial.print(c);
      if (gps.encode(c))
      { // process gps messages
        // new data...let's crack the date/time
        if (gps.time.isValid())
        {
          storedHour = gps.time.hour();
          storedMinute = gps.time.minute();
          storedSecond = gps.time.second();
          storedTenths = gps.time.centisecond();
          storedAge = gps.time.age();
          satsInView = gps.satellites.value();

          Log.verbose(F("Cracked a new time! Time is %d:%d:%d.%d, Age is %d" CR), storedHour, storedMinute, storedSecond, storedTenths, storedAge);
        }
        else
        {
          Log.warningln("Time is invalid? Could not crack!");
        }

        if (storedAge < 1000)
        {
          // it's good data (not old)...so, let's use it
          Log.verboseln("Age is good! Setting sync ready flag! %d -> %d, pps is %d, numsats %d", syncReady, true, pps, satsInView);
          syncReady = true;
        }
        else
        {
          Log.warningln("Could not set time: Data too old");
        }
      }
      syncCheck(); // check for a sync after attempting to crack a new data stream TODO: we may not need to check here if the last crack failed.
    }
    syncCheck(); // check for a sync after we've finished running through all available GPS data TODO: we may not need to check here if the last crack failed.
  }

  // check if its time to check for the dip settings TODO: move this to a scheduled task, see branch task-scheduler
  if (dipcheck++ > 400)
  { // check if 400 cycles have passed since last updating the dips
    // check if any settings have changed since last time
    unsigned int _DIPsum = 0; // create a temporary place to store out dipswitch values
    byte DIPA = ~PINA;        // ~ to invert
    byte DIPC = ~PINC;        // ~ to invert
    _DIPsum = DIPA + DIPC;

    // if any of the switches were changed, update everything
    if (_DIPsum != DIPsum || newSettingsFlag)
    {
      Log.verbose(F("Updating dip switches, DIPA set to %b, DIPC set to %b" CR), DIPA, DIPC);

      // update timezone
      unsigned int _timeZone = 0; // clearout a temporary int of memory
      for (byte i = 0; i < sizeof TimeZoneInputs / sizeof TimeZoneInputs[0]; i++)
      {                                               // read every byte in the dipswitch list
        int value = bitRead(DIPC, TimeZoneInputs[i]); // read byte (0001, 0000)
        _timeZone = _timeZone + (value << i);         // shif byte to its correct magnitude
      }

      timeZone = (_timeZone - 12) * 60; // store the new timezone value, offset by -12 (so we dont need to use a signed dip switch)

      // update clock format
      if (bitRead(DIPA, ClockFormatInput))
      {
        clockFormat = 24;
      }
      else
      {
        clockFormat = 12;
      }

      // Updates the flag letting us know if we're using localtz or not
      isUsingLocalTZInput = !bitRead(DIPA, LocalTZInput);

      // timezone
      // TODO: Most of these timezone values are HARDCODED until we find a way to easily craft dip switches that can read them.
      TimeChangeRule dipDST = {"DST", Second, Sun, Mar, 2, timeZone + 60}; // timezone offset (hrs) converted to minutes, offset by 1 hr
      TimeChangeRule dipSTD = {"STD", First, Sun, Nov, 2, timeZone};       // timezone offset (hrs) converted to minutes
      Timezone dipTZ(dipDST, dipSTD);

      dipTZ.toLocal(now(), &tcr); // setup local time (this can take thousands of cycles to compute)

      utcMinuteOffset = tcr->offset % 60;                   // strip out every full hour offset
      utcHourOffset = (tcr->offset - utcMinuteOffset) / 60; // the full hour offset

      Log.verbose(F("Offset is %d, clock format is %d, utcHourOffset is %d" CR), _timeZone, clockFormat, utcHourOffset);

      Log.verboseln(F("UTC offset minutes is %d, minute is %d, minuteOffset is %d"), getUTCOffsetMinutes(minute()), minute(), utcMinuteOffset);

      // Reset flags and sums
      newSettingsFlag = false;
      DIPsum = _DIPsum;
    }
    dipcheck = 0; // Return dipcheck to 0
  }

  // Trigger Watchdog
  wdt_reset();
}

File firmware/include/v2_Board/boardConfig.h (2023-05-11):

#ifndef _BOARD_CONFIG_H
#define _BOARD_CONFIG_H

// shift definitions
#define LATCH_PIN 8
#define CLOCK_PIN 12
#define DATA_PIN 11
#define SEGMENT_ENABLE_PIN 13

// GPS
#define GPS_PPS_PIN 2

// Dip Switches
#define DIP0 7
#define DIP1 6
#define DIP2 5
#define DIP3 4
#define DIP4 3

#endif

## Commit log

2021-11-09 Import v0.1
    [BOM.ods, gc-1000-gps.brd, gc-1000-gps.sch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]
2021-11-09 Import v0.2
    [BOM.ods, gc-1000-gps.brd, gc-1000-gps.sch]
2021-12-28 Create IO Shield for final release of gc-1000-gps
    [gc-1000-gps_IO_Shield.FCStd]
2022-01-04 Fix missing holes in io shield
    [gc-1000-gps_IO_Shield.FCStd]
2022-01-06 Import all major assembly instruction changes!
2022-01-10 Fix Snug fit when inserting db25
    [gc-1000-gps_IO_Shield.FCStd]
2022-07-12 messy but it fixes the MOTD
    [main.cpp]
2023-05-11 Switch to platformio (#3)
2023-08-07 Migrate to kicad 7 (#7)
    [BOM.ods, Stencil.FCStd, gc-1000-gps.brd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]
2024-10-31 RTC Refactor (#10)
    This was the latest build of the code and we'll be merging ontop of this later
    [gc-1000-gps.kicad_sch]
2024-10-31 button up last testing infrastructure
